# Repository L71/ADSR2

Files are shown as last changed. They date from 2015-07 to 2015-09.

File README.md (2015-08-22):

ADSR2
=====

Eurorack CMOS logic ADSR envelope generator.

* adsr2 - original version, based on separate switch ic and demultiplexer. (this one has known design bugs).

* adsr2v2 - use a dual switch multiplexer/demultiplexer for everything. Should work, but will likely not be prototyped.

* adsr2v3 - improved v2, use a 40106 buffer/inverter for IO buffers instead of transistors (=lower component count). Prototype build looks and works exactly as intended. :)

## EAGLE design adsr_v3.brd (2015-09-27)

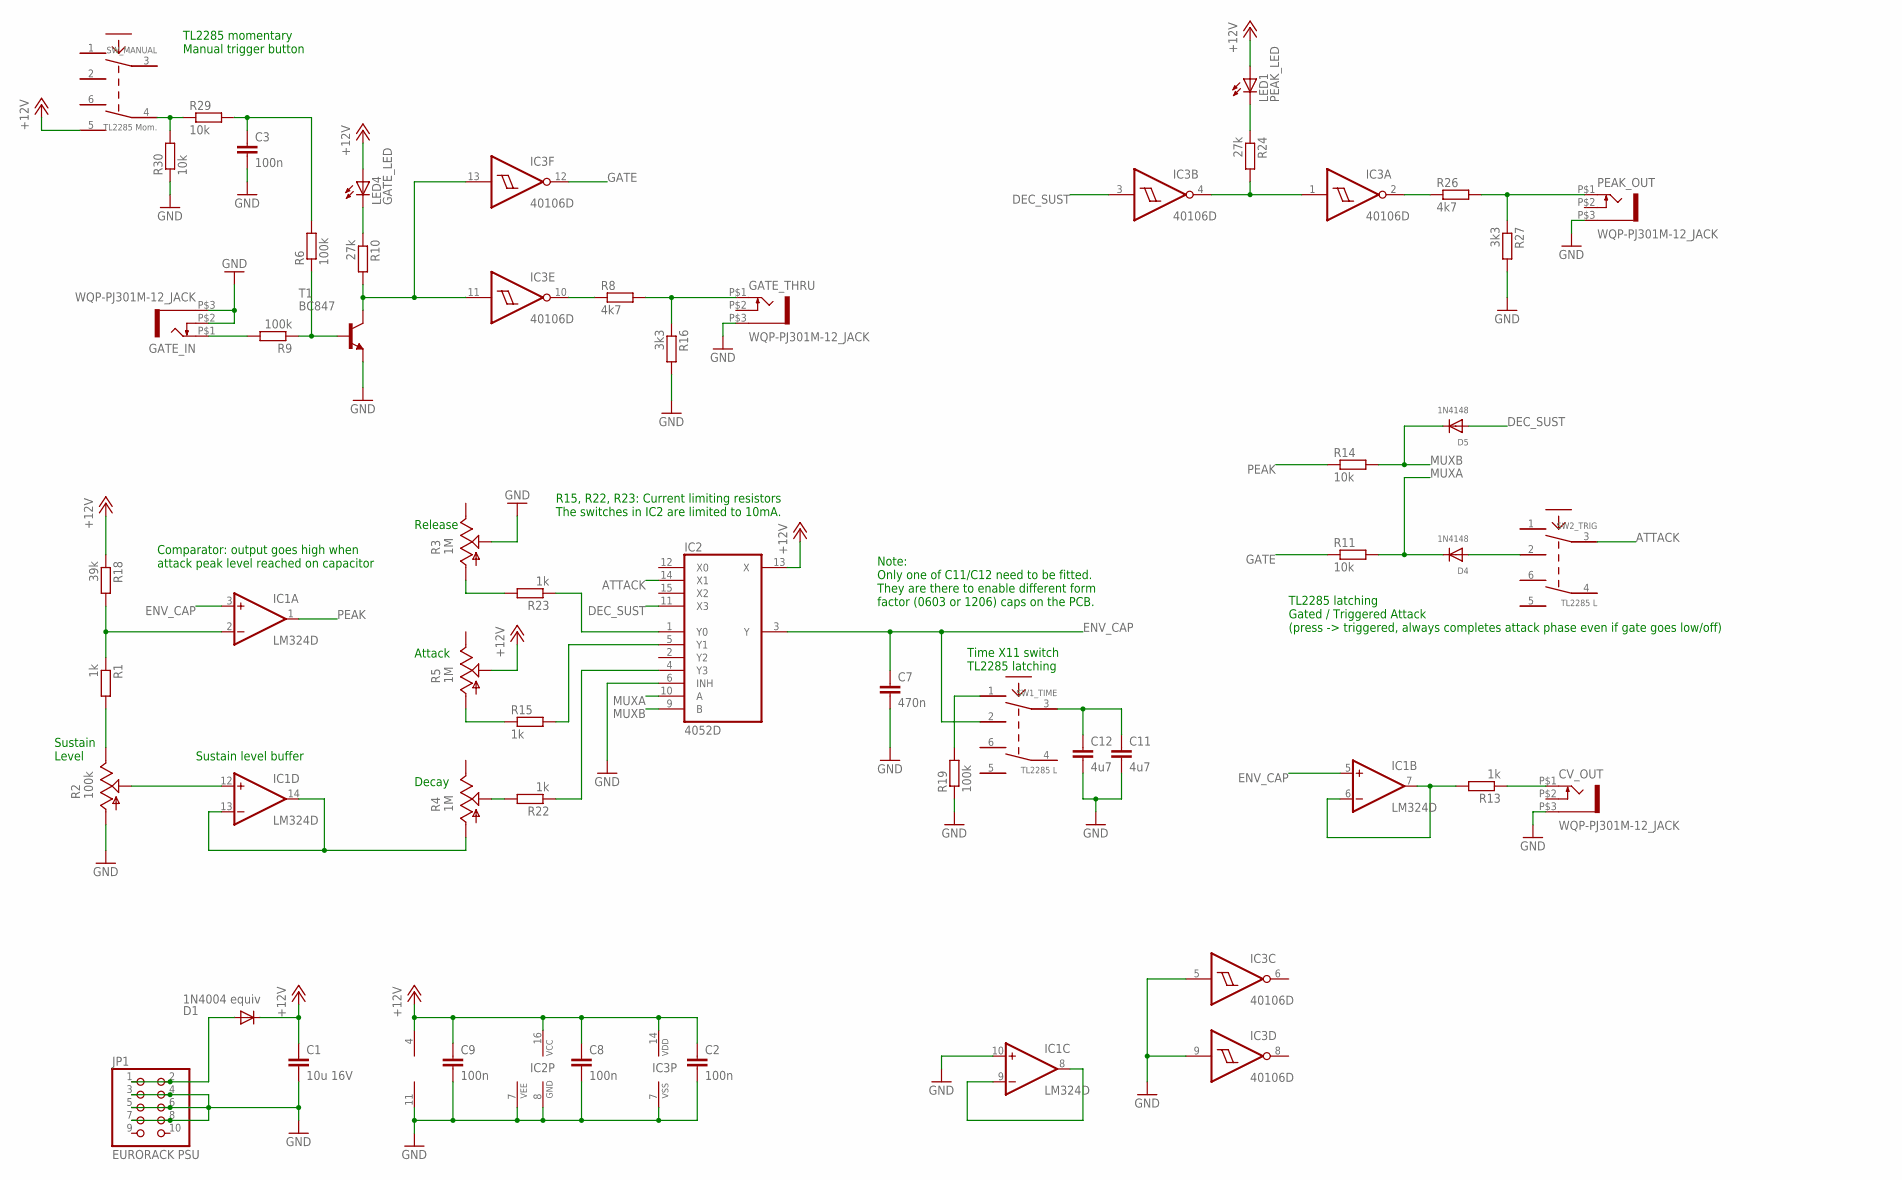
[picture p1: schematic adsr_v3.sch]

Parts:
C1: 10u 16V; C1206K
C2, C3, C8, C9: 100n; C0603K
C7: 470n; C0603K
C11: 4u7; C1206K
C12: 4u7; C0603K
CV_OUT: WQP-PJ301M-12_JACK
D1: 1N4004 equiv; DO214AA
D4, D5: 1N4148; SOD-323F
GATE_IN: WQP-PJ301M-12_JACK
GATE_THRU: WQP-PJ301M-12_JACK
IC1: LM324D; SO14
IC2: 4052D; SO16
IC3: 40106D; SO14
JP1: EURORACK PSU; 2X05
LED1: PEAK_LED; LED5MM
LED4: GATE_LED; LED5MM
PEAK_OUT: WQP-PJ301M-12_JACK
R1, R13, R15, R22, R23: 1k; R0603
R2: 100k; ALPS_POT_VERTICAL
R3, R4, R5: 1M; ALPS_POT_VERTICAL
R6, R9, R19: 100k; R0603
R8, R26: 4k7; R0603
R10, R24: 27k; R0603
R11, R14, R29, R30: 10k; R0603
R16, R27: 3k3; R0603
R18: 39k; R0603
SW1_TIME, SW2_TRIG: TL2285 L; TL2285_PCB
SW_MANUAL: TL2285 Mom.; TL2285_PCB
T1: BC847; SOT23

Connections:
+12V: C1.1, C2.1, C8.1, C9.1, D1.C, IC1.4 (V+), IC2.13 (X), IC2.16 (VCC), IC3.14 (VDD), LED1.A, LED4.A, R5.P$2 (S), R18.1, SW_MANUAL.5
ATTACK: IC2.14 (X1), SW2_TRIG.3
ATTACK_REF: IC1.2 (-IN), R1.1, R18.2
DEC_SUST: D5.A, IC2.11 (X3), IC3.3 (I)
ENV_CAP: C7.1, IC1.3 (+IN), IC1.5 (+IN), IC2.3 (Y), SW1_TIME.2
GATE: IC3.12 (O), R11.1
GATE_IN: IC3.11 (I), IC3.13 (I), R10.2, T1.3 (C)
GND: C1.2, C2.2, C3.2, C7.2, C8.2, C9.2, C11.2, C12.2, CV_OUT.P$3 (1), GATE_IN.P$2 (3), GATE_IN.P$3 (1), GATE_THRU.P$3 (1), IC1.10 (+IN), IC1.11 (V-), IC2.6 (INH), IC2.7 (VEE), IC2.8 (GND), IC3.5 (I), IC3.7 (VSS), IC3.9 (I), JP1.3, JP1.4, JP1.5, JP1.6, JP1.7, JP1.8, PEAK_OUT.P$3 (1), R2.P$3 (A), R3.P$2 (S), R16.2, R19.1, R27.2, R30.1, T1.2 (E)
MUXA: D4.C, IC2.10 (A), R11.2
MUXB: D5.C, IC2.9 (B), R14.2
unnamed: IC3.10 (O), R8.1
unnamed: GATE_IN.P$1 (2), R9.2
unnamed: D1.A, JP1.1, JP1.2
unnamed: R29.1, R30.2, SW_MANUAL.4
unnamed: IC2.1 (Y0), R23.1
unnamed: IC2.4 (Y3), R22.1
unnamed: IC1.13 (-IN), IC1.14 (OUT), R4.P$3 (A)
unnamed: IC3.2 (O), R26.1
unnamed: IC2.5 (Y1), R15.2
unnamed: CV_OUT.P$1 (2), R13.1
unnamed: IC1.6 (-IN), IC1.7 (OUT), R13.2
unnamed: GATE_THRU.P$1 (2), R8.2, R16.1
unnamed: C3.1, R6.2, R29.2
unnamed: C11.1, C12.1, SW1_TIME.3
unnamed: R19.2, SW1_TIME.1
unnamed: R6.1, R9.1, T1.1 (B)
unnamed: LED4.K (C), R10.1
unnamed: R3.P$3 (A), R23.2
unnamed: IC1.8 (OUT), IC1.9 (-IN)
unnamed: R5.P$3 (A), R15.1
unnamed: R1.2, R2.P$1 (E)
unnamed: D4.A, SW2_TRIG.2
unnamed: R4.P$2 (S), R22.2
unnamed: IC3.1 (I), IC3.4 (O), R24.2
unnamed: LED1.K (C), R24.1
unnamed: PEAK_OUT.P$1 (2), R26.2, R27.1
PEAK: IC1.1 (OUT), R14.1
SUST_LEVEL: IC1.12 (+IN), R2.P$2 (S)

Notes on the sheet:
Time X11 switch TL2285 latching
Note: Only one of C11/C12 need to be fitted. They are there to enable different form factor (0603 or 1206) caps on the PCB.
TL2285 latching Gated / Triggered Attack (press -> triggered, always completes attack phase even if gate goes low/off)
Sustain level buffer
Comparator: output goes high when attack peak level reached on capacitor
R15, R22, R23: Current limiting resistors The switches in IC2 are limited to 10mA.
TL2285 momentary Manual trigger button
Attack
Release
Decay
Sustain Level

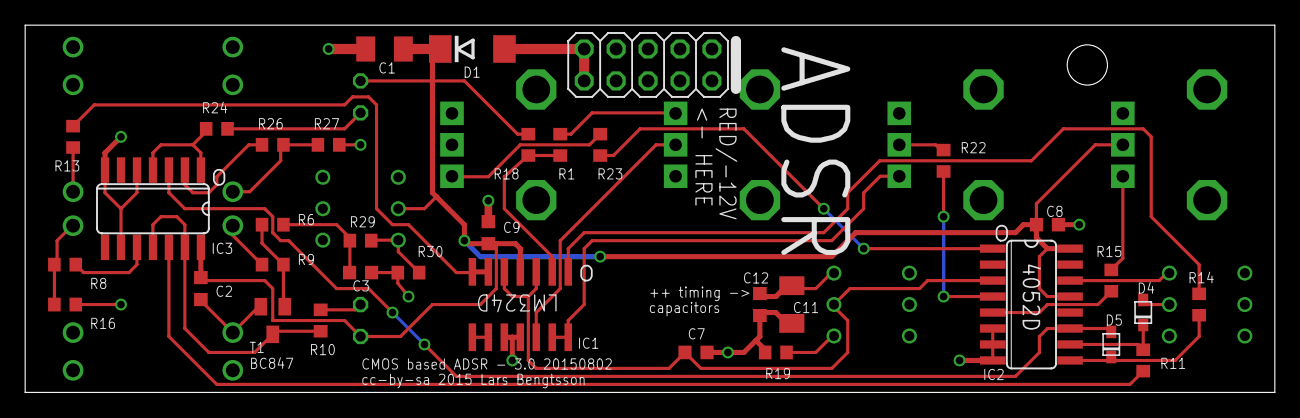
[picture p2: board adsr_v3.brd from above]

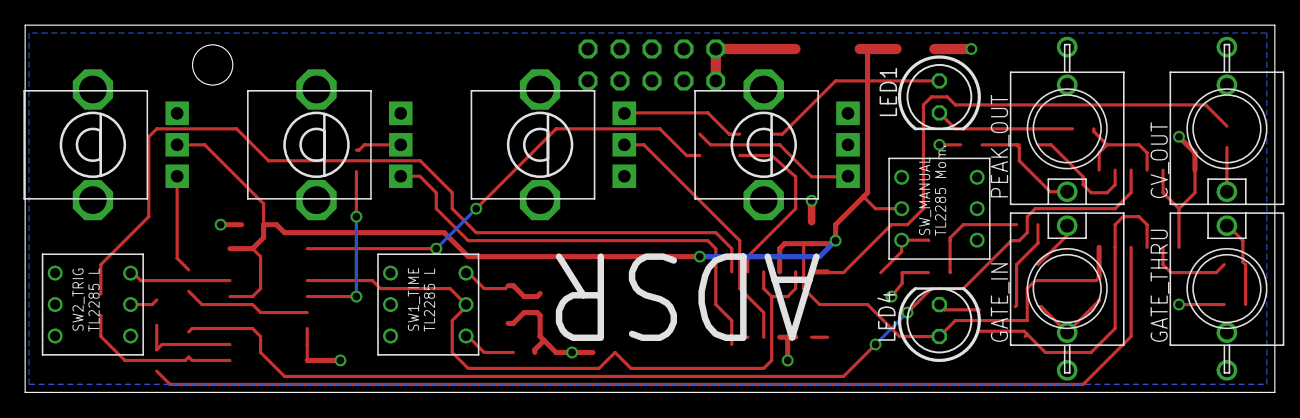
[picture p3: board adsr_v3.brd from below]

Board: 2 copper layers, 99.4 x 29.2 mm, 48 parts (13 on the bottom side), 38 nets.

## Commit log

2015-07-05 Initial commit.
    [adsr2.sch]
2015-07-07 Board added. Status LEDs removed (only GATE indicator left)
    [adsr2.brd, adsr2.sch]
2015-07-11 Changed gate IO and outputs: Gate in, Gate thru, "Attack done" trigger out, Envelope CV Out. Removed gate thru mode selector switch. Added LED #2 for "attack done" trigger. Adjusted component labels 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
    [adsr2.brd, adsr2.sch]
2015-07-12 Minor routing fixes & components moved.
    [adsr2.brd, adsr2.sch]
2015-07-12 Some more routing fixes near jacks. Updated date stamp in PCB text labels.
    [adsr2.brd]
2015-07-12 Oops, missed 2.5mm of 12V net. fixed.
    [adsr2.brd]
2015-07-18 Initial commit of V2 - design with cd4052 dual multiplexer. Down to 2 ICs, much simpler PCB.
    [adsr2_v2.brd, adsr2_v2.sch]
2015-07-18 Renamed comparator output net to "peak". Minor routing fixes on PCB.
    [adsr2_v2.brd, adsr2_v2.sch]
2015-07-18 Modified some text notes.
    [adsr2_v2.sch]
2015-07-18 Changed R1 to 1k.
    [adsr2_v2.brd, adsr2_v2.sch]
2015-07-18 Changed LEDs to 5mm footprint. Moved T3 and surrounding resistors a bit.
    [adsr2_v2.brd, adsr2_v2.sch]
2015-07-19 Bigger button holes (6mm, was 5mm). Changed line width to .01 mm as per Ponoko laser cutting specs.
2015-07-20 Added circuit to make sure peak output pulse has at least a few ms duration. Changed peak output to behave like decay+sustain gate rather than just "attack done" trigger output.
    [adsr2_v2.brd, adsr2_v2.sch]
2015-07-20 Small routing adjustments.
    [adsr2_v2.brd]
2015-07-23 Moved power diode and cap a bit to make it easier to solder components around PSU header/release pot.
    [adsr2_v2.brd]
2015-07-31 Fixed direction of potentiometers. Added debouncing circuit for manual trig button. Updated date/version label.
    [adsr2_v2.brd, adsr2_v2.sch]
2015-08-02 Add v3. Replaces most transistor buffers with pieces of a 40106. Simplified diode logic too.
    [adsr_v3.brd, adsr_v3.sch]
2015-08-02 Moved PSU capacitor a bit.
    [adsr_v3.brd]
2015-08-02 Minor routing & labeling fixes. Replaced schematic A3 document frame with other type.
    [adsr_v3.brd, adsr_v3.sch]
2015-08-04 Moved PSU diode and capacitor a bit. Diode has a rather bit and wide package, we better leave a bit of space around it.
    [adsr_v3.brd]
2015-08-08 Changed some resistors from 100k to 10k; this works with the used BC847 transistors. (Breadboard prototype used BC547B)
    [adsr2.brd, adsr2.sch]
2015-08-20 Changed LED current resistors to 27k, better match with the 350-400 mcd LEDs.
    [adsr_v3.brd, adsr_v3.sch]
2015-09-27 Added hole. Needed to hold front panel in place when panel can't be held in place by potentiometers.
    [adsr_v3.brd]
2016-01-11 Adjusted panel bottom edge and holes downwards 1/40" to better fit racks w 3mm screws.

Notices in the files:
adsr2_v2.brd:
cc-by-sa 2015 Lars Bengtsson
